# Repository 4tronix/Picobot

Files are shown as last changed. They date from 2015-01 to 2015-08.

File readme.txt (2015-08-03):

Picobot Released Files
======================

All files are Licensed under Creative Commons BY-SA
See creativecommons.org/licenses/by-sa/3.0/ for details

CP2102 programming cable requires drivers from: silabs.com/products/mcu/Pages/USBtoUARTBridgeVCPDrivers.aspx

When using the Arduino IDE, select board type UNO. The Picobot is fully compatible with the UNO

Note - v1.3 and later Versions
==============================
Version 1.3 and 1.4 of the Picobot PCB use neopixel LEDs instead of standard RGB LEDs and this means that they
are individually addressable so you can have different colours on the left and the right.

The versions of the software below with the suffix '2' indicate that they are built for use with neopixels

You must install the Arduino library FastLED2 for these examples to work.

Picobot Software
================
DemoAll - Uses the Mode button to switch between 5 different demos. After pressing the button it flashes the LEDs the number of times for the following demos:
	1. Flash all the LEDs
	2. Line Follower
	3. Light Seeker
	4. Obstacle avoider
	5. Constant distance
AllLeds - Lights all the LEDs
BlinkTest - Flashes all the LEDs one at a time
AnalogTest - outputs analog values from light and line following sensors to Serial Monitor
MotorTest - Turns the motors Forwards, Reverse, Spin Left, Spin Right, Halt in turn
Utra - Outputs the distance reading from teh Ultrasonic sensor to the Serial Monitor
Runaway - Uses the Picobot library and ultrasonic sensor to avoid objects
LineFollower - Simple line follower script using the RGB LEDs to show direction

Picobot Schematics
==================
Picobot<xy>.sch is the Eagle schematic for version x.y
Picobot<xy>.brd is the Eagle board file for version x.y

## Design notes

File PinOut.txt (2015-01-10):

Picobot Pinout
==============

Picobot uses the ATMega328P-AU chip which has an extra 2 analog inputs (8 total)
The additional 2 analog inputs (A6 and A7) do not have an associated digital I/O so cannot be used as digital inputs and you cannot set internal pull-up or pull-down resistors

Digital I/O
===========
D0 - RX
D1 - TX
D2 - Left Motor A
D3 - Left Motor B (PWM available)
D4 - Right Motor A
D5 - Right Motor B (PWM available)
D6 - Rear (White) LED
D7 - CSN (used for nRF24L01 module)
D8 - CE (used for nRF24L01 module)
D9 - Red control output for front RGB LEDs
D10 - Tact button input (capacitor debounced, requires internal pullup)
D11 - MOSI (used for nRF24L01 module and SPI)
D12 - MISO (used for nRF24L01 module and SPI)
D13 - SCLK (used for nrF24L01 module, SPI and D13 Blue LED)

Analog Inputs
=============
A0 - Left LDR (requires internal pullup)
A1 - Right LDR (requires internal pullup)
A2 - Green control output for front RGB LEDs
A3 - Blue control output for front RGB LEDs
A4 - Ping output to ultrasonic sensor (also SDA pin for I2C)
A5 - Echo input from ultrasonic sensor (also SCLK pin for I2C)
A6 - Left line sensor input
A7 - Right line sensor input

Notes:
======
1. You can use the 4-pin ultrasonic header as a general purpose I2C connector if required, so adding a display or acceleromter, etc is easy

2. The nRF24L01 header can double as an SPI breakout, but note that you will hve to pickup 5V from the programming header

3. Combining the programming header and the nRF24L01 header allows you access to all the ICSP pins so you can flash the bootloader orinstall your program directly without using a bootloader. Not required for "normal" users :)

4. Pin2 on the programming header (labelled 'R') is directly connected to the Reset pin on the processor

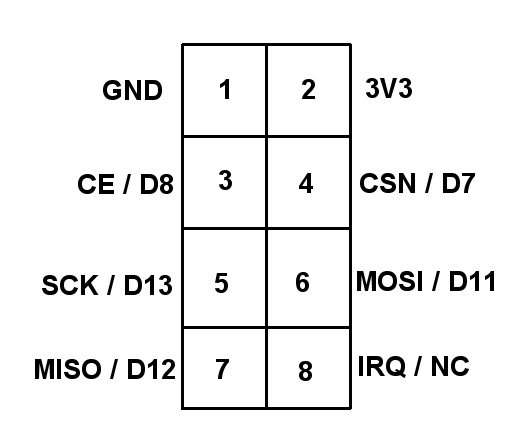
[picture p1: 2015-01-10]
nRF_Connector.jpg

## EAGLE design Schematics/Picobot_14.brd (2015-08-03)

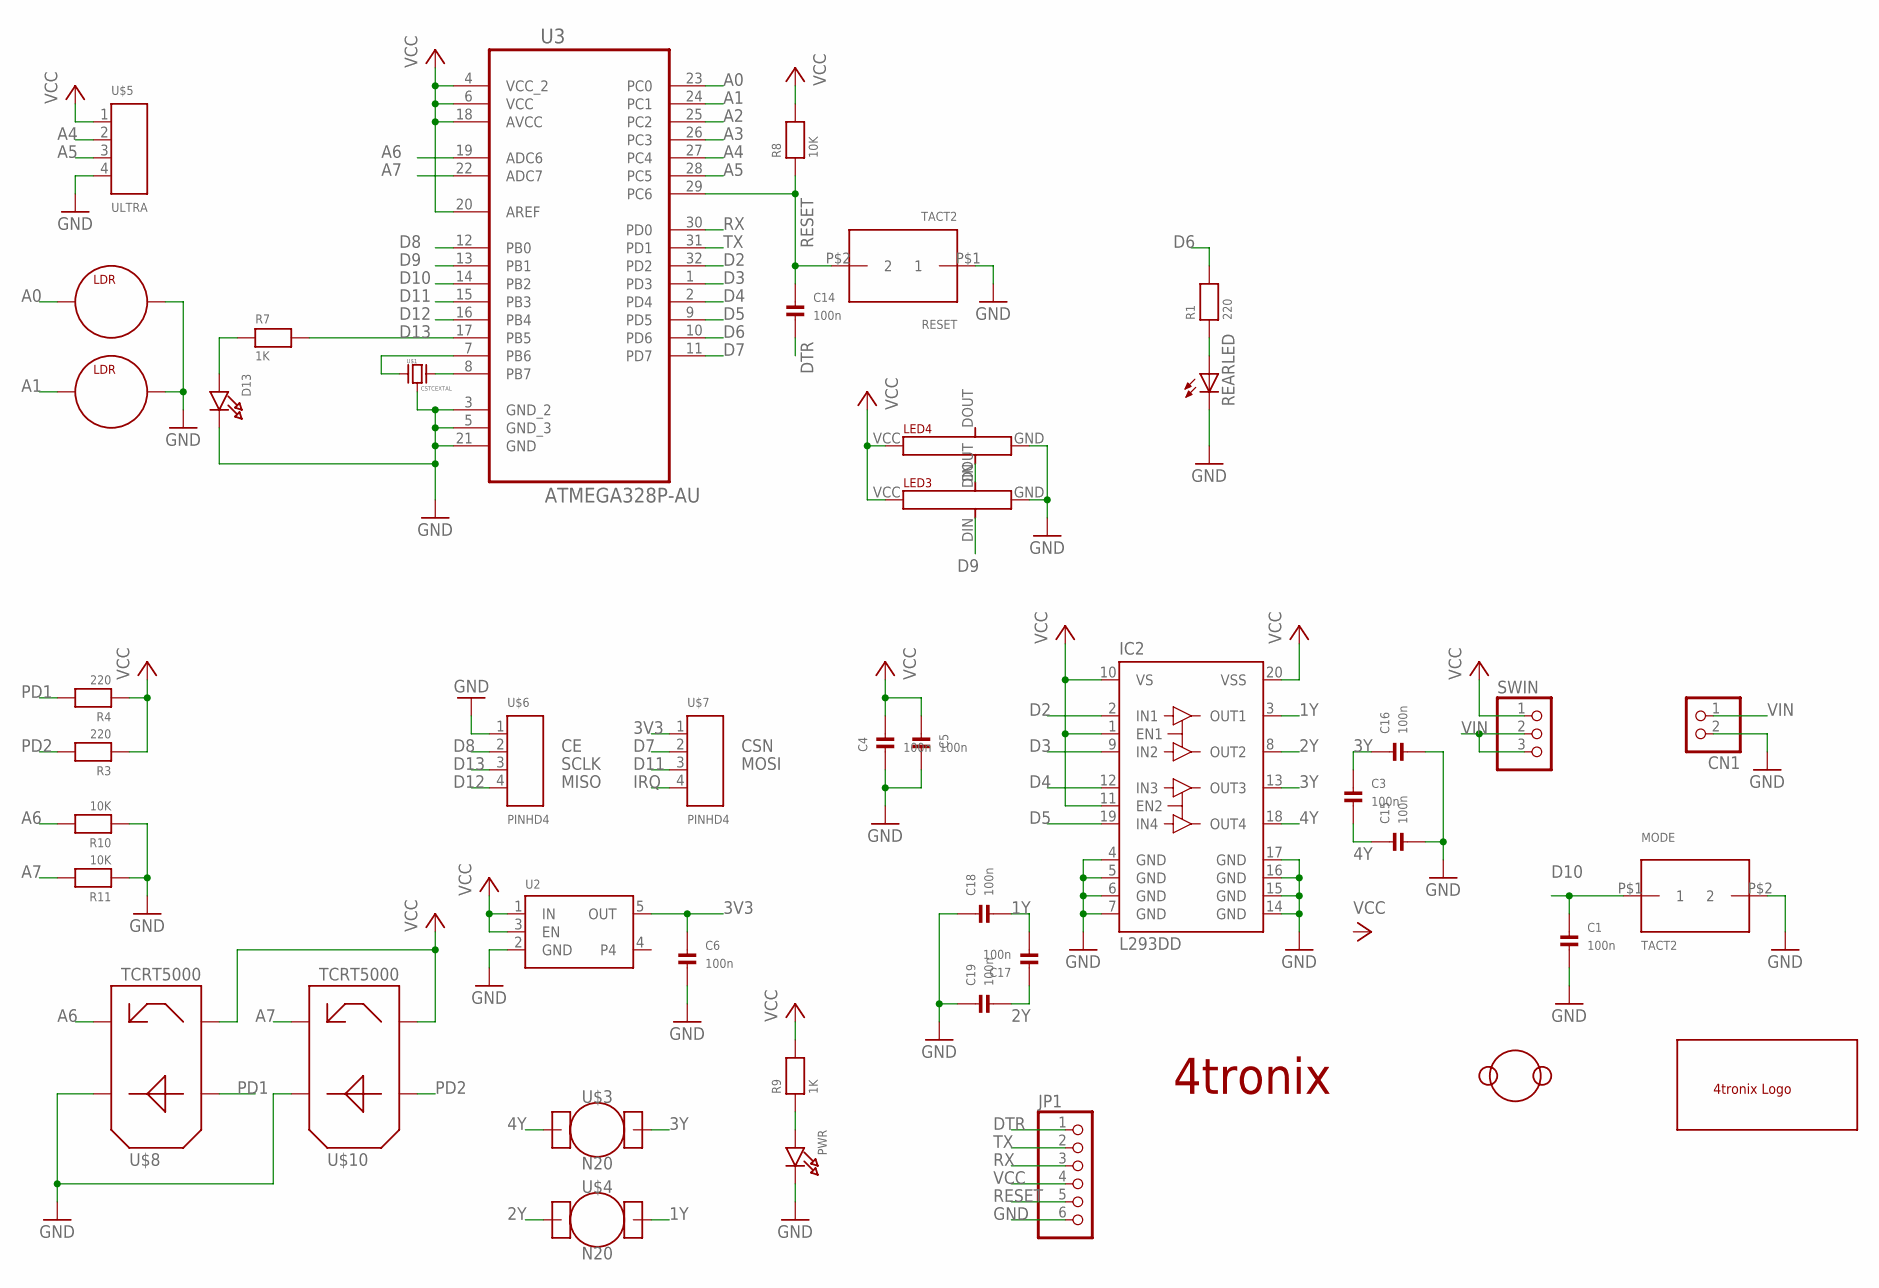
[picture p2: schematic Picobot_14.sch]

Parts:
C1, C3, C4, C5, C6, C14, C15, C16, C17, C18, C19: 100n; _0603MP
CN1: JST_2PIN-THM; JST-PH-2-THM
D13: LED0805_NOOUTLINE; CHIPLED_0805_NOOUTLINE
IC2: L293DD; SO20
JP1: PINHD-1X6CB; 1X06-CLEANBIG
LDR1, LDR2: LDR
LED3, LED4: WS2812B
MODE: TACT2; TACT2-PIN
PWR: LED0805_NOOUTLINE; CHIPLED_0805_NOOUTLINE
R1, R3, R4: 220; 0603-MINI
R7, R9: 1K; 0603-MINI
R8, R10, R11: 10K; 0603-MINI
REARLED: LED3MM
RESET: TACT2; TACT2-PIN
SWIN: PINHD-1X3CB; 1X03-CLEANBIG
U2: VREG_SOT23-5; SOT23-5
U3: ATMEGA328P-AU; QFP80P900X900X120-32N
U$1: CSTCEXTAL
U$2: LOGO
U$3, U$4: N20
U$5: ULTRA; PINHD4
U$6, U$7: PINHD4
U$8, U$10: TCRT5000
U$9: DFRBALL

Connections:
1Y: C17.2, C18.2, IC2.3 (OUT1), U$4.MTRA (MTRB)
2Y: C17.1, C19.2, IC2.8 (OUT2), U$4.MTRB (MTRA)
3V3: C6.1, U2.5 (OUT), U$7.1
3Y: C3.1, C16.1, IC2.13 (OUT3), U$3.MTRA (MTRB)
4Y: C3.2, C15.1, IC2.18 (OUT4), U$3.MTRB (MTRA)
A0: LDR1.A, U3.23 (PC0)
A1: LDR2.A, U3.24 (PC1)
A2: U3.25 (PC2)
A3: U3.26 (PC3)
A4: U3.27 (PC4), U$5.2
A5: U3.28 (PC5), U$5.3
A6: R10.2, U3.19 (ADC6), U$8.TR2
A7: R11.2, U3.22 (ADC7), U$10.TR2
D2: IC2.2 (IN1), U3.32 (PD2)
D3: IC2.9 (IN2), U3.1 (PD3)
D4: IC2.12 (IN3), U3.2 (PD4)
D5: IC2.19 (IN4), U3.9 (PD5)
D6: R1.2, U3.10 (PD6)
D7: U3.11 (PD7), U$7.2
D8: U3.12 (PB0), U$6.2
D9: LED3.DIN (DI), U3.13 (PB1)
D10: C1.1, MODE.P$1 (1), U3.14 (PB2)
D11: U3.15 (PB3), U$7.3
D12: U3.16 (PB4), U$6.4
D13: R7.2, U3.17 (PB5), U$6.3
DTR: C14.2, JP1.1
GND: C1.2, C4.2, C5.2, C6.2, C15.2, C16.2, C18.1, C19.1, CN1.2 (1), D13.C, IC2.4 (GND), IC2.5 (GND), IC2.6 (GND), IC2.7 (GND), IC2.14 (GND), IC2.15 (GND), IC2.16 (GND), IC2.17 (GND), JP1.6, LDR1.K, LDR2.K, LED3.GND, LED4.GND, MODE.P$2 (2), PWR.C, R10.1, R11.1, REARLED.K (C), RESET.P$1 (1), U2.2 (GND), U3.3 (GND_2), U3.5 (GND_3), U3.21 (GND), U$1.G, U$5.4, U$6.1, U$8.LED2, U$10.LED2
IRQ: U$7.4
unnamed: D13.A, R7.1
unnamed: R1.1, REARLED.A
unnamed: U3.7 (PB6), U$1.X1
unnamed: U3.8 (PB7), U$1.X2
unnamed: LED3.DOUT (DO), LED4.DIN (DI)
unnamed: PWR.A, R9.1
PD1: R4.2, U$8.LED1
PD2: R3.2, U$10.LED1
RESET: C14.1, JP1.5, R8.1, RESET.P$2 (2), U3.29 (PC6)
RX: JP1.3, U3.30 (PD0)
TX: JP1.2, U3.31 (PD1)
VCC: C4.1, C5.1, IC2.1 (EN1), IC2.10 (VS), IC2.11 (EN2), IC2.20 (VSS), JP1.4, LED3.VCC, LED4.VCC, R3.1, R4.1, R8.2, R9.2, SWIN.1, U2.1 (IN), U2.3 (EN), U3.4 (VCC_2), U3.6 (VCC), U3.18 (AVCC), U3.20 (AREF), U$5.1, U$8.TR1, U$10.TR1
VIN: CN1.1 (2), SWIN.2, SWIN.3

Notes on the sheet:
4tronix
SCLK
MISO
CSN
MOSI

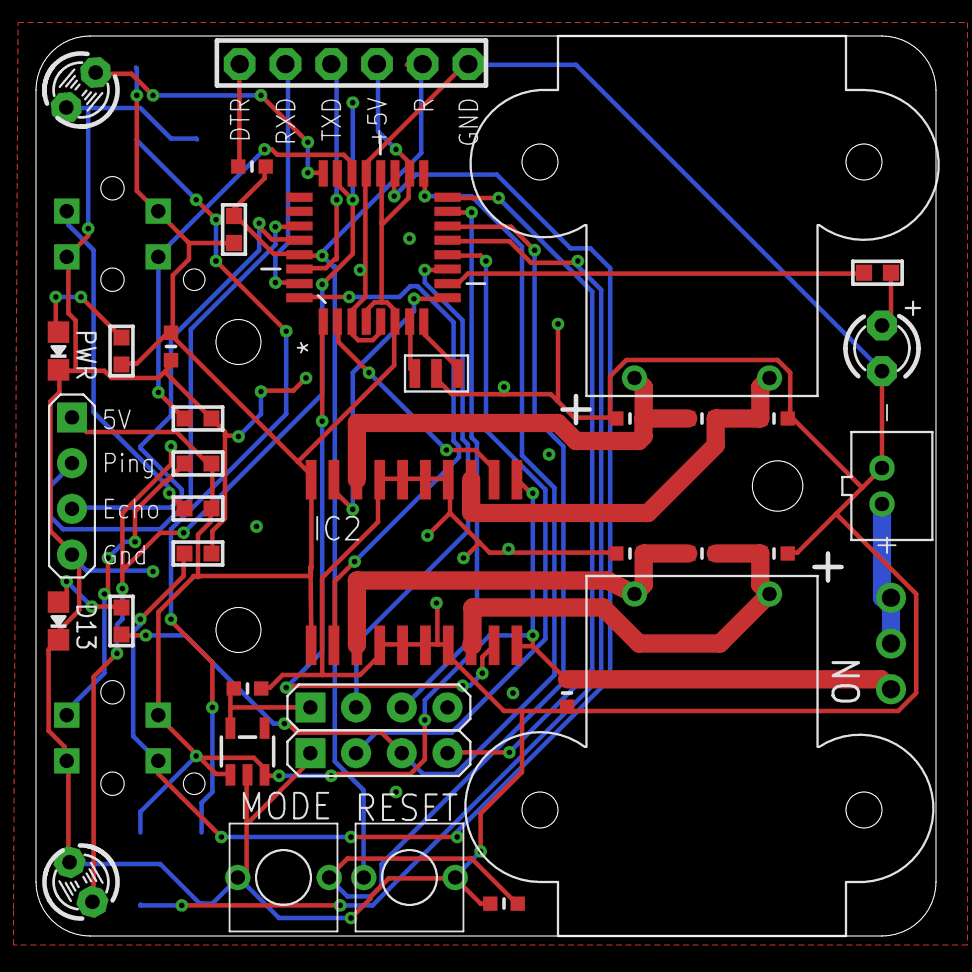
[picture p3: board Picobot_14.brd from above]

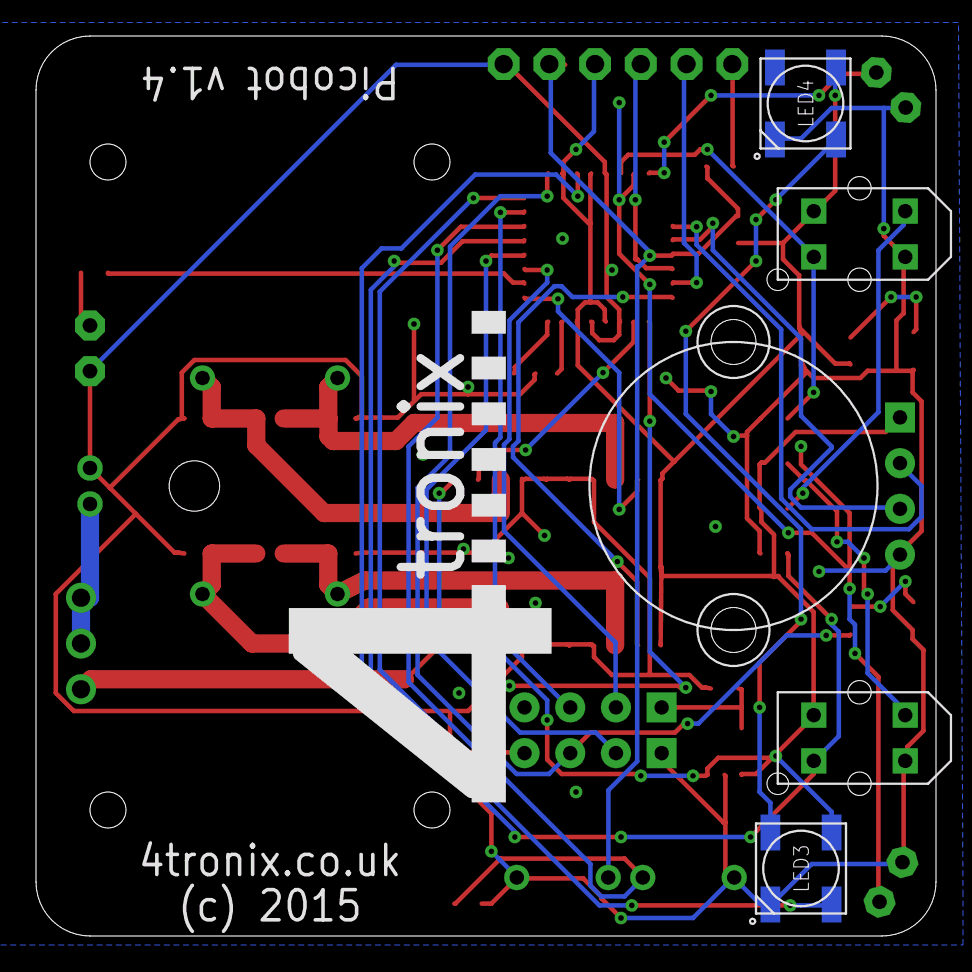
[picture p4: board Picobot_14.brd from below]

Board: 2 copper layers, 50.0 x 50.0 mm, 44 parts (6 on the bottom side), 38 nets.

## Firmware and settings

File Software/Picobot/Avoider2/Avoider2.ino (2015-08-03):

/*
  Demo All
  Shows a number of features of the PicoBot and uses the Mode switch to change Operation
  
  1) Flashing Lights
  2) Line Follower
  3) Light seeker
  4) Obstacle avoider (not every Picobot has ultrasonic)
  5) Constant distance (not every Picobot has ultrasonic)
  
  Purpose: Initial test program for shipping
 
  This example code is licensed under CC-BY-SA https://creativecommons.org/licenses/by-sa/3.0/
 */

#include "FastSPI_LED2.h"

// WS2812B definitions
#define NUM_LEDS 2
#define DATA_PIN 9
CRGB leds[NUM_LEDS];

int L1 = 2, L2 = 3, L3 = 4, L4 =5; // Pins connected to Motor driver L298N H-Bridge module
#define blue 13  // Blue LED pin
#define white 6  // Rear white LED
#define LEFTLINE   A6  // Left Line Sensor (Analog) - High values = Reflection (no line)
#define RIGHTLINE  A7  // Right Line Sensor (Analog)
#define SWITCH 10  // Mode button on D10
#define LEFTLDR A0 // Left light sensor
#define RIGHTLDR A1 // Right light sensor
int trigPin = A4;   // Analog pin 4 used for the Ping Pin (Trig)
int echoPin = A5;   // Analog pin 5 used for the Echo Pin (Echo)
unsigned long duration, inches;
int indec, cmdec;
int inchconv = 147; // ratio between pulse width and inches
int cmconv = 59;    // ratio between pulse width and cm



#define LEVEL 300  // level below which it must be over a line
#define HYSTERESIS 50  // difference in analog readings for LDR to make it turn in light follower

#define FLASH 1
#define LINE 2
#define LIGHT 3
#define AVOIDER 4
#define CONSTDIST 5
#define LASTPROG 5

int state = 4;  // initial state is 1) Line Follower
int lastButton = HIGH;  // Initial state of button is OFF

// the setup routine runs once when you press reset:
void setup()
{                
  FastLED.addLeds<WS2812B, DATA_PIN, RGB>(leds, NUM_LEDS);
  allOff();
  // initialize the digital pins we will use as an output.
  pinMode(L1, OUTPUT);     
  pinMode(L2, OUTPUT);     
  pinMode(L3, OUTPUT);     
  pinMode(L4, OUTPUT);
  pinMode(blue, OUTPUT);     
  pinMode(white, OUTPUT);     
  pinMode(trigPin, OUTPUT);
  digitalWrite(SWITCH, HIGH);  // add pullup to mode button
  digitalWrite(LEFTLDR, HIGH);
  digitalWrite(RIGHTLDR, HIGH);
  Serial.begin(115200);
  FlashAll(200);  // Sign on with a slow flashing display
}

// the loop routine runs over and over again forever:
// runs one iteration of the relevant program, then checks the mode button
// moves to next state if mode button pressed and flashes LED correct number of times
void loop()
{
  state = 4;
  switch (state)
  {
    case 1:
      flashLEDs();
      break;
    case 2:
      lineFollow();
      break;
    case 3:
      lightSeek();
      break;
    case 4:
      obstacleAvoid();
      break;
    case 5:
      constDistance();
      break;
  }
  if (getButton()==1)
  {
    halt(0);
    state++;
    if (state > LASTPROG)
      state = 1;
    flashCount(state);
    Serial.println("New state: " + String(state));
  }
}

void flashLEDs()  // State 1
{
  FlashAll(30);
}

void lineFollow()  // State 2
{
  if (analogRead(LEFTLINE) < LEVEL)
  {
    setColour(HIGH, LOW, LOW); // Red
    leftSpin(10);
  }
  else if (analogRead(RIGHTLINE) < LEVEL)
  {
    setColour(LOW, HIGH, LOW); // Green
    rightSpin(10);
  }
  else
  {
    setColour(LOW, LOW, HIGH);  // Blue
    forward(10);
  }
}

void lightSeek()  // State 3
{
  int ldrL = analogRead(LEFTLDR);
  int ldrR = analogRead(RIGHTLDR);
  if (ldrL < (ldrR - HYSTERESIS))
  {
    setColour(HIGH, LOW, LOW); // Red
    leftSpin(10);
  }
  else if (ldrR < (ldrL - HYSTERESIS))
  {
    setColour(LOW, HIGH, LOW); // Green
    rightSpin(10);
  }
  else
  {
    setColour(LOW, LOW, HIGH);  // Blue
    forward(10);
  }
}

void obstacleAvoid() // State 4
{
  int cm = getDistance();
  Serial.println("Distance: " + String(cm));
  if (cm  < 8)
  {
    setColour(HIGH, HIGH, LOW);  // Yellow
    reverse(1000);
    setColour(LOW, HIGH, LOW);  // Green
    rightSpin(1000);
  }
  else
  {
    setColour(LOW, LOW, HIGH);  // Blue
    forward(10);
  }
}

void constDistance()  // State 5
{
  int cm = getDistance();
  Serial.println("Distance: " + String(cm));
  if (cm  < 10)
  {
    setColour(HIGH, HIGH, LOW);  // Yellow
    reverse(10);
  }
  else if (cm > 10)
  {
    setColour(LOW, LOW, HIGH);  // Blue
    forward(10);
  }
  else
  {
    setColour(HIGH, HIGH, HIGH);  // White
    halt(10);
  }
}

void FlashAll(int wait)
{
  allOff();
  digitalWrite(blue, HIGH);   // turn the LED on (HIGH is the voltage level)
  delay(wait);
  digitalWrite(blue, LOW);   // turn the LED on (HIGH is the voltage level)
  digitalWrite(white, HIGH);   // turn the LED on (HIGH is the voltage level)
  delay(wait);
  digitalWrite(white, LOW);   // turn the LED on (HIGH is the voltage level)
  delay(wait);
  setAll(40,0,0);
  delay(wait);
  setAll(0,40,0);
  delay(wait);
  setAll(0,0,40);
  delay(wait);
  setAll(40,40,40);
  delay(wait);
}

void setColour(int r, int g, int b)
{
  // For v1.3, convert to FastLED methods
  setAll(r*40, g*40, b*40);
//  digitalWrite(RED, r);
//  digitalWrite(GREEN, g);
//  digitalWrite(BLUE, b);
}

// robMove routine switches the correct inputs to the L298N for the direction selected.
void robMove(int l1, int l2, int r1, int r2)
{
//  return;  // uncomment the return; for desktop coding!
  digitalWrite(L2, l1);
  digitalWrite(L1, l2);
  digitalWrite(L4, r1);
  digitalWrite(L3, r2);  
}

void reverse(int wait)
{
  Serial.println("Moving backward");
  robMove(LOW, HIGH, HIGH, LOW);
  delay(wait);
}

void forward(int wait)
{
  Serial.println("Moving forward");
  robMove(HIGH, LOW, LOW, HIGH);
  delay(wait);
}

void rightSpin(int wait)
{
  Serial.println("Spinning right");
  robMove(HIGH, LOW, HIGH, LOW);
  delay(wait);
}

void leftSpin(int wait)
{
  Serial.println("Spinning left");
  robMove(LOW, HIGH, LOW, HIGH);
  delay(wait);
}

void halt(int wait)
{
  Serial.println("Stopping");
  robMove(LOW, LOW, LOW, LOW);
  delay(wait);
}

int getButton()
{
  int newB = digitalRead(SWITCH);
//  Serial.println("Button = " + String(newB));
  if (newB==LOW and lastButton==HIGH)
  {
    lastButton = LOW;
    return 1;
  }
  lastButton = newB;
  return 0;
}

void flashCount(int count)
{
  for (int i=0; i<count; i++)
  {
    setAllLEDs(HIGH);
    delay(300);
    setAllLEDs(LOW);
    delay(300);
  }
}

void setAllLEDs(int val)
{
  digitalWrite(blue, val);
  digitalWrite(white, val);
  setColour(LOW, val, LOW);
}

int getDistance()
{
  int rval;
  digitalWrite(trigPin, LOW);
  delayMicroseconds(2);
  digitalWrite(trigPin, HIGH);
  delayMicroseconds(10);
  digitalWrite(trigPin, LOW);
  duration = pulseIn(echoPin, HIGH, 38000L);  // Set timeout to 38mS
  rval = microsecondsToCentimeters(duration);
  Serial.println(rval);
  return rval;
}

long microsecondsToCentimeters(long microseconds)
{
  return microseconds / cmconv;
}

void allOff()
{
  for (int i=0; i<NUM_LEDS; i++)
    leds[i] = 0;
  FastLED.show();
}

void setAll(int _red, int _green, int _blue)
{
  for (int i=0; i<NUM_LEDS; i++)
  {
    leds[i].g = _red;
    leds[i].r = _green;
    leds[i].b = _blue;
  }
  FastLED.show();
}

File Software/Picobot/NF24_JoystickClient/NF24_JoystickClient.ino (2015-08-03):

/* YourDuinoStarter Example: nRF24L01 Receive Joystick values
 
 - WHAT IT DOES: Receives data from another transceiver with
 2 Analog values from a Joystick or 2 Potentiometers
 Displays received values on Serial Monitor
 - SEE the comments after "//" on each line below
 - CONNECTIONS: nRF24L01 Modules See:
 http://arduino-info.wikispaces.com/Nrf24L01-2.4GHz-HowTo
 1 - GND
 2 - VCC 3.3V !!! NOT 5V
 3 - CE to Arduino pin 9
 4 - CSN to Arduino pin 10
 5 - SCK to Arduino pin 13
 6 - MOSI to Arduino pin 11
 7 - MISO to Arduino pin 12
 8 - UNUSED
 
 - V1.00 11/26/13
 Based on examples at http://www.bajdi.com/
 Questions: terry@yourduino.com */

/*-----( Import needed libraries )-----*/
#include <SPI.h>
#include <nRF24L01.h>
#include <RF24.h>
/*-----( Declare Constants and Pin Numbers )-----*/
#define CE_PIN   8
#define CSN_PIN 7

// NOTE: the "LL" at the end of the constant is "LongLong" type
const uint64_t pipe = 0xE8E8F0F0E1LL; // Define the transmit pipe
int motor1a = 2;
int motor1b = 3;
int motor2a = 4;
int motor2b = 5;

/*-----( Declare objects )-----*/
RF24 radio(CE_PIN, CSN_PIN); // Create a Radio
/*-----( Declare Variables )-----*/
int joystick[2];  // 2 element array holding Joystick readings

void setup()   /****** SETUP: RUNS ONCE ******/
{
  pinMode(motor1a, OUTPUT); 
  pinMode(motor1b, OUTPUT); 
  pinMode(motor2a, OUTPUT); 
  pinMode(motor2b, OUTPUT);
  Serial.begin(9600);
  delay(1000);
  Serial.println("Nrf24L01 Receiver Starting");
  radio.begin();
  radio.openReadingPipe(1,pipe);
  radio.startListening();
  ;

}//--(end setup )---


void loop()   /****** LOOP: RUNS CONSTANTLY ******/
{
  if ( radio.available() )
  {
    // Read the data payload until we've received everything
    bool done = false;
    digitalWrite(motor1a, LOW);
    digitalWrite(motor2a, LOW);
    while (!done)
    {
      // Fetch the data payload
      done = radio.read( joystick, sizeof(joystick) );
      Serial.print("X = ");
      Serial.print(joystick[0]);
      Serial.print(" Y = ");      
      Serial.println(joystick[1]);
      if ( joystick[0] < 200 ) {
        digitalWrite(motor1b, HIGH);
      } 
      else {
        digitalWrite(motor1b, LOW);
      }
      if ( joystick[1] < 200 ) {
        digitalWrite(motor2b, HIGH);
      } else {
        digitalWrite(motor2b, LOW);
      }
    }
  }
  else
  {    
    Serial.println("No radio available");
  }

}//--(end main loop )---

/*-----( Declare User-written Functions )-----*/

//NONE
//*********( THE END )***********

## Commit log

2015-01-10 First Release of Software
    [Picobot_10.brd, Picobot_10.sch]
2015-01-10 Added reset pin info
2015-01-12 Revised Motor Pins for V1.0
2015-08-03 Added FastLED2 Library
    Arduino Library file required for Neopixel examples
2015-08-03 Schematic Updates
    Includes neopixels and layout changes
    [Picobot_14.brd, Picobot_14.sch]

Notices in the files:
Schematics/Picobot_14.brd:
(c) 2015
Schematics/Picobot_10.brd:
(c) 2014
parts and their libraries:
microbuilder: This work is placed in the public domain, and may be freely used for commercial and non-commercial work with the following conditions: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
